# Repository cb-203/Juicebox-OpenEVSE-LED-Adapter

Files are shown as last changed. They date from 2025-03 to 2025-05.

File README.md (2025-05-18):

# JuiceBox-OpenEVSE LED Adapter

This printed circuit board design adapts the 
[OpenEVSE v1 JuiceBox replacement board](https://store.openevse.com/collections/all-products/products/replacement-electronics-for-juicebox-v1-metal-black-and-orange)'s 
LED connector to work with the LED harnesses in later model eMotorWerks JuiceBox units.

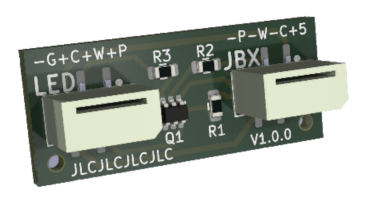
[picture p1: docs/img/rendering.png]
Rendering of the circuit board


Prior to the redesign and release of the "v2" JuiceBox model following the acquisition of 
eMotorWerks by EnelX in late 2017, many (most?) "v1" JuiceBox units were provided 
with LED harnesses requiring +5V power to each LED with a common ground return path (+ + + -). 
However, earlier models of the v1 design included harnesses having the opposite polarity (- - - +).

The first implementations of the OpenEVSE replacement board were designed around the 
earlier model JuiceBoxes with the (- - - +) orientation and were quickly found to be incompatible 
with the later model JuiceBox LED harnesses.  Due to the way the LED harnesses were installed into 
the cover of the JuiceBox unit, reorienting or replacing the LEDs was considered impractical. 
Although OpenEVSE have since developed a common ground variant of the replacement board, 
this project aims to bridge the gap between the earlier model OpenEVSE boards and later model 
JuiceBox LED harnesses by translating the voltages from one orientation to the other using a small 
adapter board.

Files in this project are implemented in [KiCad](https://www.kicad.org) version 8.0.

$${\color{white}.}$$

## Board Layout and Components

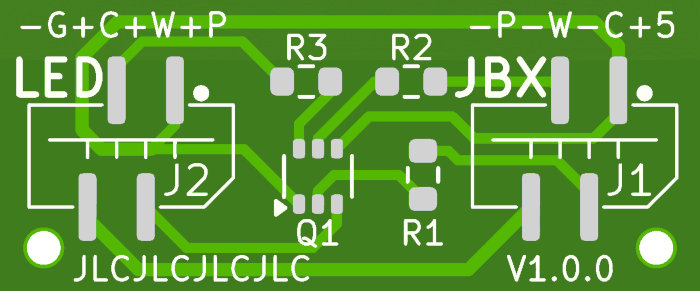
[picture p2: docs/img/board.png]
Front view of the circuit board


* J1, J2: 4-pin FFC connector, vertical, 1.0 mm pitch
* R1, R2: 2.4 kOhm resistor, 0603 package
* R3: 75 Ohm resistor, 0603 package
* Q1: Dual PNP/PNP transistors, SOT-363 package
* F1: Flat Flexible Cable (FFC), 4-pin, 1.0 mm pitch, 10 cm length, same-side, insert into J1

$${\color{white}.}$$

## The Schematic

Electrical circuit schematic diagram

As shown in the schematic diagram, the PWR pin on the OpenEVSE board (J1, pin 4) is used as the 
source of common ground for the LEDs.  Since the power light is always on, it is presumed that 
this pin will never be switched off while the other LEDs are in use.  Therefore, power from the 
+5V pin 1 is routed directly to the LED harness's green power LED (J2, pin 1), and the PWR pin 
(now treated as the source for ground) is routed to the harness's common ground (J2, pin 4).

The other two LEDs are switched on ground.  When the LEDs are off, the WIFI and/or CHG pins on 
the OpenEVSE board are floating.  When on, these pins are connected to ground.  To convert this 
behavior into +5V power for each LED, a pair of PNP transistors is used.  +5V is routed to the 
emitter of each transistor, and the collector is connected to each corresponding LED.  When 
negative voltage is applied to the base of each transistor via the WIFI and CHG pins on the 
controller board, the transistor is opened allowing +5V current to flow through to the LED, 
returning on the common ground lane.

Resistors are used on each transistor's base pin to limit the current draw from the emitter 
through the base.  An additional resistor is also added to the red CHG LED to reduce its 
current draw.  Through experimentation, without the added resistance, this LED was found to pull 
about 22 mA of current, while the green and blue LEDs pull closer to 13 mA.  Even with the added 
resistance, the red LED subjectively appears to provide very similar brightness to the other 
two lights.

$${\color{white}.}$$

## Current flow

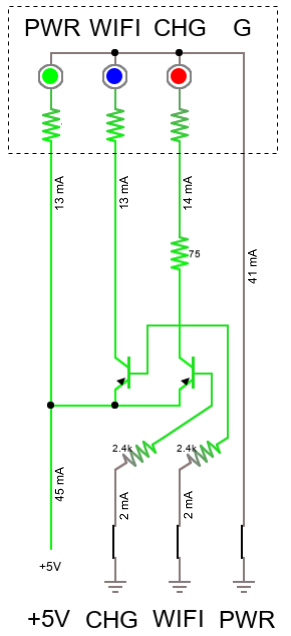
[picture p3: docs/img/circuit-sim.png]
Electrical circuit simulation


Simulating the circuit with proposed resistor values using the 
[Falstad Circuit Simulator](https://www.falstad.com), 
this diagram shows the approximate current at each section of the circuit.  At worst case, 
the board is expected to pull no more than 45 to 50 mA. 

The resistors shown adjacent to the LEDs are included in the existing LED harness. 
In the simulation, the values for these resistors were set to approximate the current 
measured at each LED.  As noted above, the red LED was found to pull about 22 mA without 
additional resistance, while the green and blue LEDs each pull about 13 mA.

$${\color{white}.}$$

$${\color{white}.}$$

$${\color{white}.}$$

$${\color{white}.}$$

$${\color{white}.}$$

$${\color{white}.}$$

$${\color{white}.}$$

## Prototype

Proof-of-concept prototype boards fabricated in March 2025 using [JLCPCB.com](https://jlcpcb.com) 
board manufacture with component assembly:

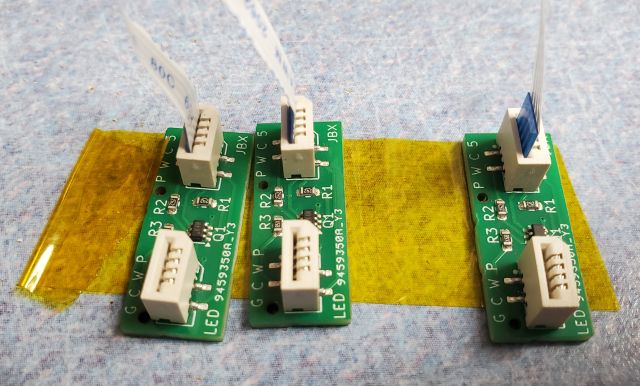
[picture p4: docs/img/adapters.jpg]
Collection of three adapters on a piece of yellow tape


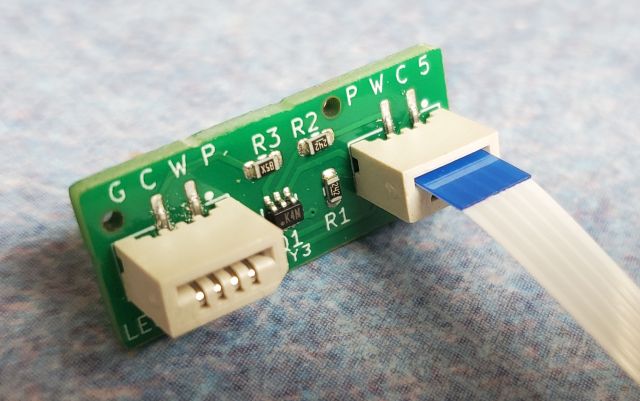
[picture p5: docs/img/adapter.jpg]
Closeup of a single adapter board with FFC cable


Adapter installed into a JuiceBox Pro 32 with OpenEVSE v1 replacement board.  The adapter is 
affixed to the side wall of the JuiceBox enclosure with foam mounting tape.

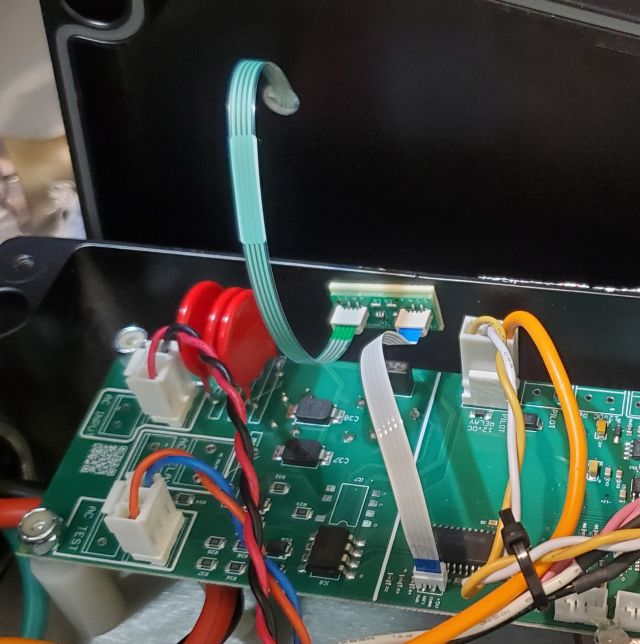
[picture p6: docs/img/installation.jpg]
View of the board installed into the JuiceBox


All lights are on for a few seconds when the device is first powered on.  When ready, only the 
green LED is illuminated.  While charging, the red LED is also lit.  The blue LED is used to 
indicate an error state (not pictured) but will also momentarily light up when the unit is 
powered off (also not pictured).

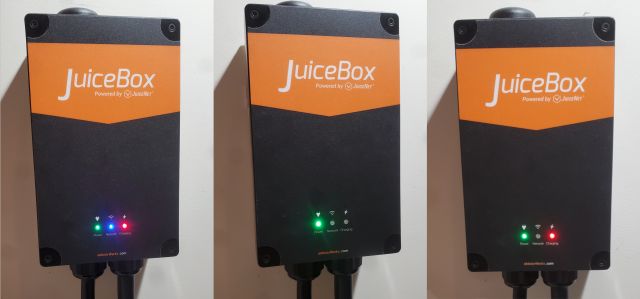
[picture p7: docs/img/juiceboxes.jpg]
Three photos of a JuiceBox showing working LEDs


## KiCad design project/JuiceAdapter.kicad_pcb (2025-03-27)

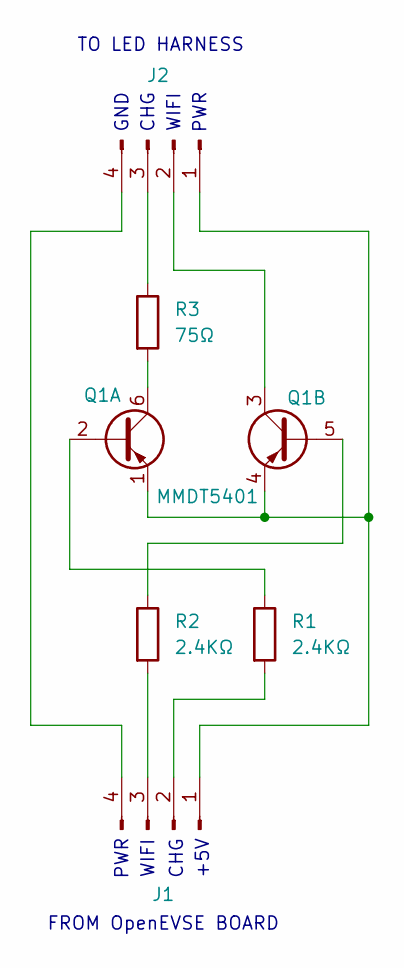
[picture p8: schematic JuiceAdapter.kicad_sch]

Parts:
J1, J2: Conn_01x04_Pin; STWXE FC38-04N0-AHS; LCSC PN C7499262
Q1: MMDT5401; SOT-363_SC-70-6; LCSC PN C968396
R1, R2: 2.4KΩ; R_0603_1608Metric; LCSC PN C22940
R3: 75Ω; R_0603_1608Metric; LCSC PN C4275

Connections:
unnamed: J1.1, J2.1, Q1.1 (E1), Q1.4 (E2)
unnamed: J1.2, R1.2
unnamed: J1.3, R2.2
unnamed: J1.4, J2.4
unnamed: J2.2, Q1.3 (C2)
unnamed: J2.3, R3.1
unnamed: Q1.2 (B1), R1.1
unnamed: Q1.6 (C1), R3.2
unnamed: Q1.5 (B2), R2.1

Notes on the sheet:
PWR
GND
TO LED HARNESS
FROM OpenEVSE BOARD
+5V
WIFI
CHG

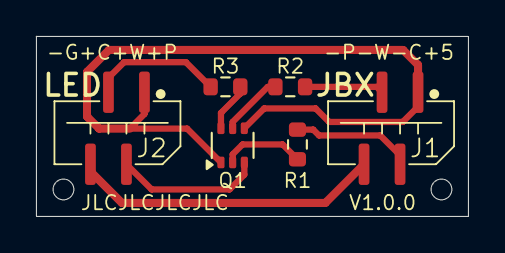
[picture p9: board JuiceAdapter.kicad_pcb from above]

Board: 2 copper layers, 24.0 x 10.0 mm, 6 parts (0 on the bottom side), 9 nets.

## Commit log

2025-03-23 Clarified resistor values on schematic and PCB.
    [JuiceAdapter.kicad_pcb, JuiceAdapter.kicad_sch]
2025-03-23 Updated schematic size and rendering background on README.
2025-03-25 Clarified project organization, updated README
    [JuiceAdapter.kicad_pcb, JuiceAdapter.kicad_sch]
2025-03-26 Relocated drill and placement origin
    [JuiceAdapter.kicad_pcb]
2025-03-27 Adjusted traces for single-sided board
    [JuiceAdapter.kicad_pcb]
2025-05-18 Add board layout to documentation
